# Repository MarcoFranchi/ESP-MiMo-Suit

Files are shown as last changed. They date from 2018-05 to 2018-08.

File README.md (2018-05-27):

# ESP-MiMo-Suit
Lighting MIcroMOdule for Home Automation based on ESP8266 WiFi Module
The MiMo suit is currently composed of three modules:
MiMo-Light (control Light)
MiMo-Button (two buttons)
MiMo-3Realy (three relays)

Common feature:

Compatible with existing electrical plant
minimal changes to the electrical system are necessary, the modules can be installed in the wall box, it is not necessary to install new wires, they can work with pushbuttons or standard switches
Safety and super reliable Buttom/Switch control.
no restriction on the length of the connection wires of the Buttons/Switch (the botton/switch are controlled with the AC Voltage and optoisolated versus the module logic)
Solid State Relay
Optoisolated enad zero cross detect relay for safety and no mechanical and electrical noise
Compatible with ESP Firmware
Espurna, ESP Easy, Tasmota and all firmware for ESP can be used for control

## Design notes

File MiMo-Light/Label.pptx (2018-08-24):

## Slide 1

ESP MiMo-Light
2018- V2.0
By Marco Franchi
Input: 230V/50Hz
Output: 460W MAX!
Unit ID:
Name:

https://github.com/MarcoFranchi/ESP-MiMo-Suit

Switch

Load

F

N

N

AC-in

F

ESP MiMo-Light
2018- V2.0
By Marco Franchi
Input: 230V/50Hz
Output: 460W MAX!
Unit ID:
Name:

https://github.com/MarcoFranchi/ESP-MiMo-Suit

Switch

Load

F

N

N

AC-in

F

ESP MiMo-Light
2018- V2.0
By Marco Franchi
Input: 230V/50Hz
Output: 460W MAX!
Unit ID:
Name:

https://github.com/MarcoFranchi/ESP-MiMo-Suit

Switch

Load

F

N

N

AC-in

F

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

https://github.com/MarcoFranchi/ESP-MiMo-Suit

Switch

Load

F

N

N

AC-in

F

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

https://github.com/MarcoFranchi/ESP-MiMo-Suit

Switch

Load

F

N

N

AC-in

F

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

https://github.com/MarcoFranchi/ESP-MiMo-Suit

Switch

Load

F

N

N

AC-in

F

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

https://github.com/MarcoFranchi/ESP-MiMo-Suit

Switch

Load

F

N

N

AC-in

F

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

https://github.com/MarcoFranchi/ESP-MiMo-Suit

Switch

Load

F

N

N

AC-in

F

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

https://github.com/MarcoFranchi/ESP-MiMo-Suit

Switch

Load

F

N

N

AC-in

F

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

https://github.com/MarcoFranchi/ESP-MiMo-Suit

Switch

Load

F

N

N

AC-in

F

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

https://github.com/MarcoFranchi/ESP-MiMo-Suit

Switch

Load

F

N

N

AC-in

F

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

https://github.com/MarcoFranchi/ESP-MiMo-Suit

Switch

Load

F

N

N

AC-in

F

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

https://github.com/MarcoFranchi/ESP-MiMo-Suit

Switch

Load

F

N

N

AC-in

F

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

https://github.com/MarcoFranchi/ESP-MiMo-Suit

Switch

Load

F

N

N

AC-in

F

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

https://github.com/MarcoFranchi/ESP-MiMo-Suit

Switch

Load

F

N

N

AC-in

F

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

https://github.com/MarcoFranchi/ESP-MiMo-Suit

Switch

Load

F

N

N

AC-in

F

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

https://github.com/MarcoFranchi/ESP-MiMo-Suit

Switch

Load

F

N

N

AC-in

F

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

https://github.com/MarcoFranchi/ESP-MiMo-Suit

Switch

Load

F

N

N

AC-in

F

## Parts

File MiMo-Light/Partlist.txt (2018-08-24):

Partlist

Exported from MiMo-Light-V2.0.brd at 05/06/2018 17:47

EAGLE Version 8.7.0 Copyright (c) 1988-2018 Autodesk, Inc.

Assembly variant: 

Part     Value             Package                        Library             Position (mm)         Orientation

C3       100uF             1210                           SparkFun-Capacitors (2.53 16.26)          MR90
C4       10uF              1206                           SparkFun-Capacitors (41.7 34.62)          MR90
C5       10uF              1206                           SparkFun-Capacitors (28.54 37.3)          MR180
D1                         MINIMELF                       diode               (28.75 33.75)         MR0
FUSE     THERMALFUSE       TE5                            Marco-Lib           (17.63 8.27)          R270
IC1      MID400SD          SOP254P1030X508-8N             SamacSys_Parts      (39.75 18.89)         MR90
IC2      ZLDO1117G33TA     SOT230P700X180-4N              SamacSys_Parts      (35.46 36.24)         MR90
J1       1844252           SHDR6W100P0X350_1X6_2240X920X7 SamacSys_Parts      (21.98 2.38)          R0
JP1                        JP1                            jumper              (22.88 30.7)          R0
K1       CPC1966Y          CPC1966Y                       SamacSys_Parts      (23.2 15.9)           R270
LED2                       CHIPLED_1206                   led                 (22.2 41.05)          R270
LS1      CSS-0575B-SMT-TR  CSS-0575B-SMT-TR               SamacSys_Parts      (22.25 37)            R180
MDL1                       ESP8266-ESP12E                 ESP8266-ESP12E      (10.14 27.93)         R0
R1       220               R1206                          eagle-ltspice       (18.58 25.29)         MR180
R2       10K               R1206                          eagle-ltspice       (34.74 28.85)         MR0
R3       S07K11            S07K11                         varistor            (41.07 6.07)          R270
R4       10K               R1206                          eagle-ltspice       (19.93 19.15)         MR180
R5       1k                R1206                          eagle-ltspice       (29.65 24.6)          MR0
R6       10K               R1206                          eagle-ltspice       (18.48 32.1)          MR0
R7       1k                R1206                          eagle-ltspice       (29.56 21.1)          MR0
R8       1k                R1206                          eagle-ltspice       (18.36 28.9)          MR180
R9       220               R1206                          eagle-ltspice       (41.22 28.85)         MR0
R10      47K 2W            R2512                          eagle-ltspice       (29.44 15.23)         MR180
R12      4K7               R1206                          eagle-ltspice       (28.5 28.75)          MR0
T1       BC817-25LT1SMD    SOT23-BEC                      transistor-npn      (22.75 35.75)         MR0
U2       HLK-PM013W        HLK-PM01                       HLK-PM01            (35.67 25.52)         R90
X2       TSW-104-08-G-D-RA TSW-104-08-G-D-RA              con-samtec          (8.5 8)               R0

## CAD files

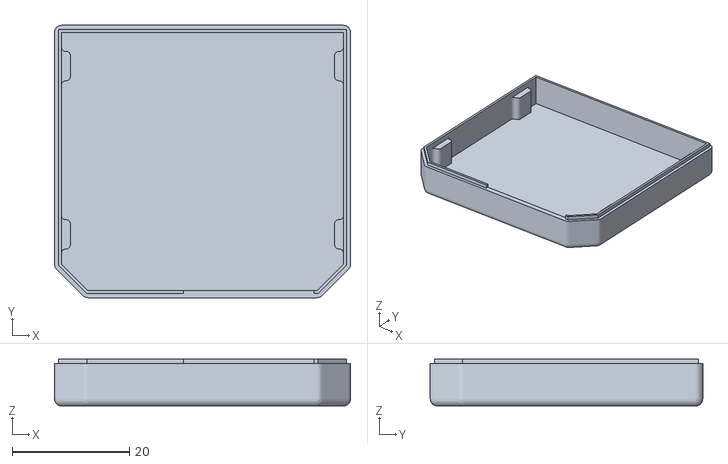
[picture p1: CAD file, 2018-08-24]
MiMo-Light/Buttom.stl
50.4 x 46.4 x 8.00

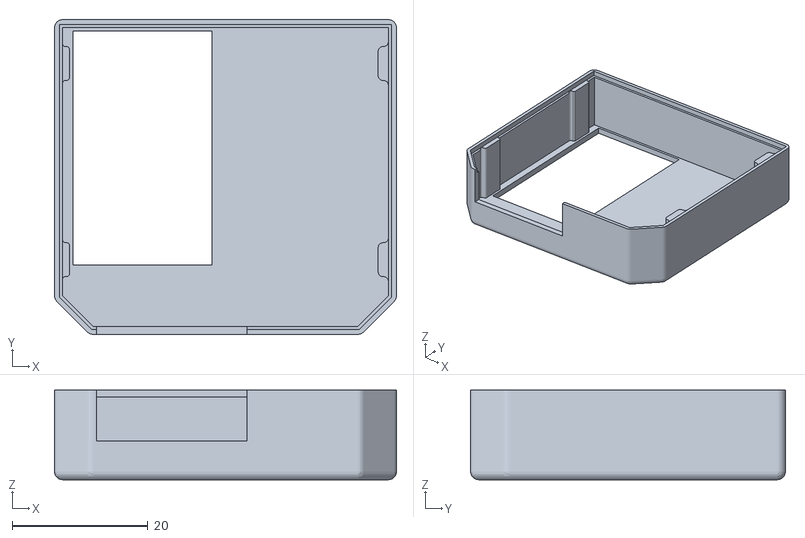
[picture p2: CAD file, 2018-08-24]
MiMo-Light/Top.stl
50.4 x 46.4 x 13.2

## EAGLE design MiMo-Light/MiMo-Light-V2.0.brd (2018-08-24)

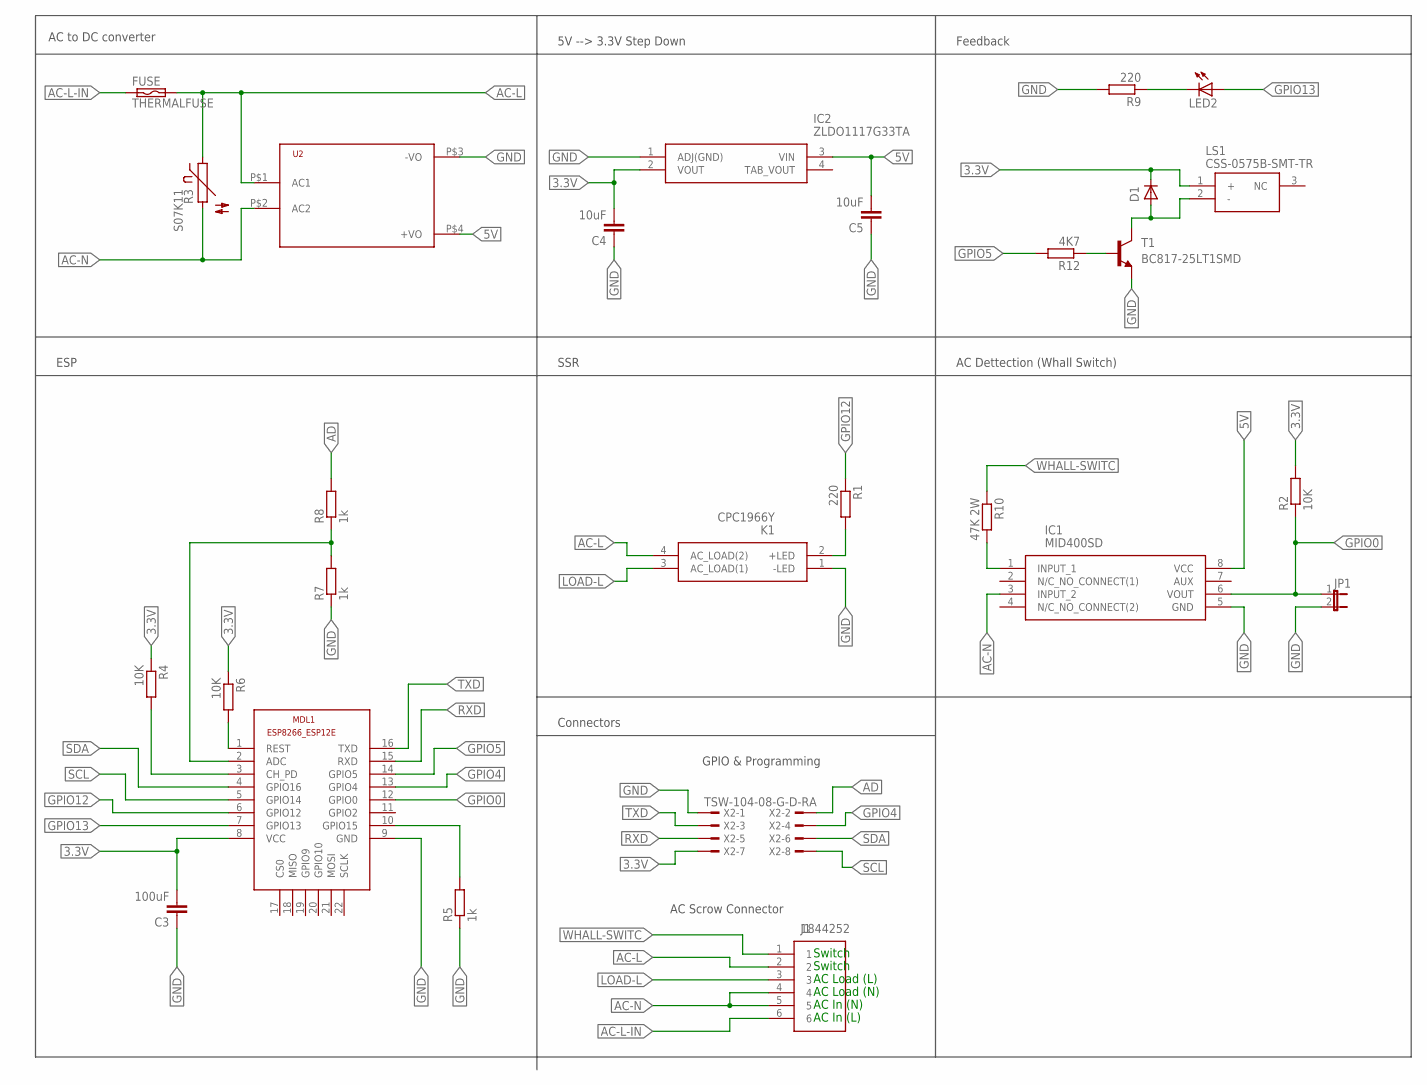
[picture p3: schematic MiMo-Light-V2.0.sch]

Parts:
C3: 100uF; 1210
C4, C5: 10uF; 1206
D1: DIODE-MINIMELF; MINIMELF
FUSE: THERMALFUSE; TE5
IC1: MID400SD; SOP254P1030X508-8N
IC2: ZLDO1117G33TA; SOT230P700X180-4N
J1: 1844252; SHDR6W100P0X350_1X6_2240X920X7
JP1: JP1E; JP1
K1: CPC1966Y
LED2: LEDCHIPLED_1206; CHIPLED_1206
LS1: CSS-0575B-SMT-TR
MDL1: ESP8266-12EESP8266-ESP12E; ESP8266-ESP12E
R1, R9: 220; R1206
R2, R4, R6: 10K; R1206
R3: S07K11
R5, R7, R8: 1k; R1206
R10: 47K 2W; R2512
R12: 4K7; R1206
T1: BC817-25LT1SMD; SOT23-BEC
U2: HLK-PM013W; HLK-PM01
X2: TSW-104-08-G-D-RA

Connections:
3.3V: C3.2, C4.2, D1.C, IC2.2 (VOUT), LS1.1 (+), MDL1.8 (VCC), R2.2, R4.1, R6.1, X2.7
5V: C5.2, IC1.8 (VCC), IC2.3 (VIN), U2.P$4 (+VO)
AC-DETECT: IC1.1 (INPUT_1), R10.2
AC-L: FUSE.2, J1.2, K1.4 (AC_LOAD(2)), R3.1, U2.P$1 (AC1)
AC-L-IN: FUSE.1, J1.6
AC-N: IC1.3 (INPUT_2), J1.4, J1.5, R3.2, U2.P$2 (AC2)
AD: R8.2, X2.2
ADC: MDL1.2 (ADC), R7.2, R8.1
GND: C3.1, C4.1, C5.1, IC1.5 (GND), IC2.1 (ADJ(GND)), JP1.2, K1.1 (-LED), MDL1.9 (GND), R5.1, R7.1, R9.2, T1.E, U2.P$3 (-VO), X2.1
GPIO0: IC1.6 (VOUT), JP1.1, MDL1.12 (GPIO0), R2.1
GPIO4: MDL1.13 (GPIO4), X2.4
GPIO5: MDL1.14 (GPIO5), R12.2
GPIO12: MDL1.6 (GPIO12), R1.1
GPIO13: LED2.A, MDL1.7 (GPIO13)
LOAD-L: J1.3, K1.3 (AC_LOAD(1))
unnamed: LED2.C, R9.1
unnamed: K1.2 (+LED), R1.2
unnamed: D1.A, LS1.2 (-), T1.C
unnamed: MDL1.3 (CH_PD), R4.2
unnamed: R12.1, T1.B
unnamed: MDL1.10 (GPIO15), R5.2
unnamed: MDL1.1 (REST), R6.2
RXD: MDL1.15 (RXD), X2.5
SCL: MDL1.5 (GPIO14), X2.8
SDA: MDL1.4 (GPIO16), X2.6
TXD: MDL1.16 (TXD), X2.3
WHALL-SWITC: J1.1, R10.1

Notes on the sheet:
SSR
AC to DC converter
5V --> 3.3V Step Down
Feedback
AC Dettection (Whall Switch)
Connectors
GPIO & Programming
AC Scrow Connector
Switch
AC Load (L)
AC Load (N)
AC In (N)
AC In (L)
ESP

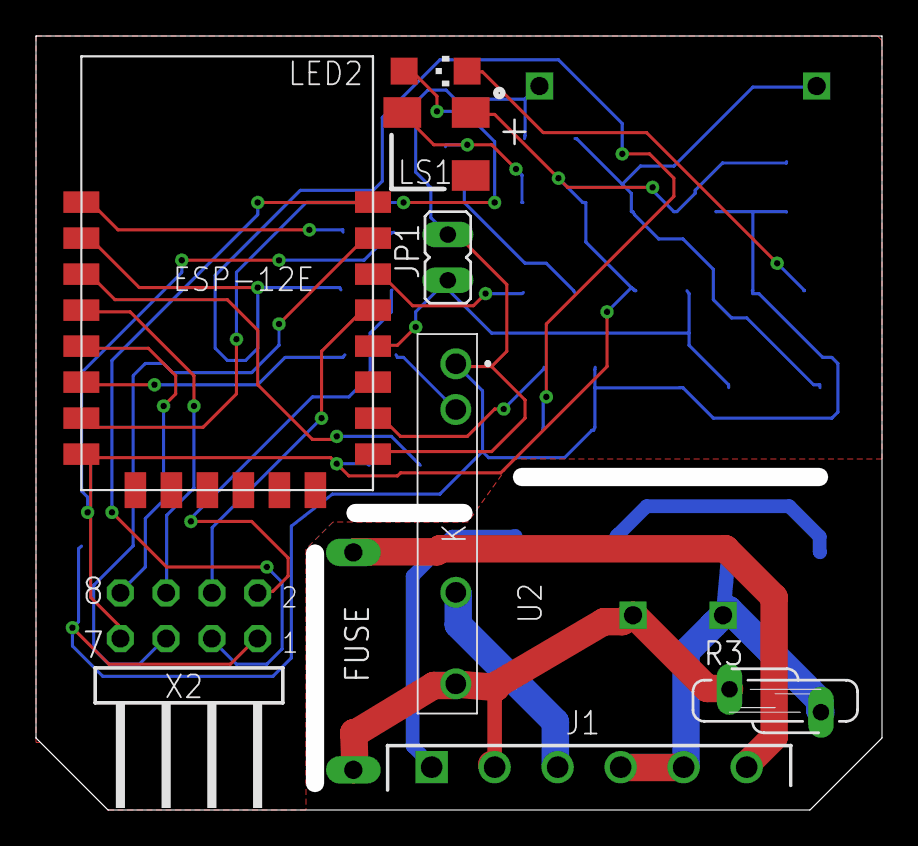
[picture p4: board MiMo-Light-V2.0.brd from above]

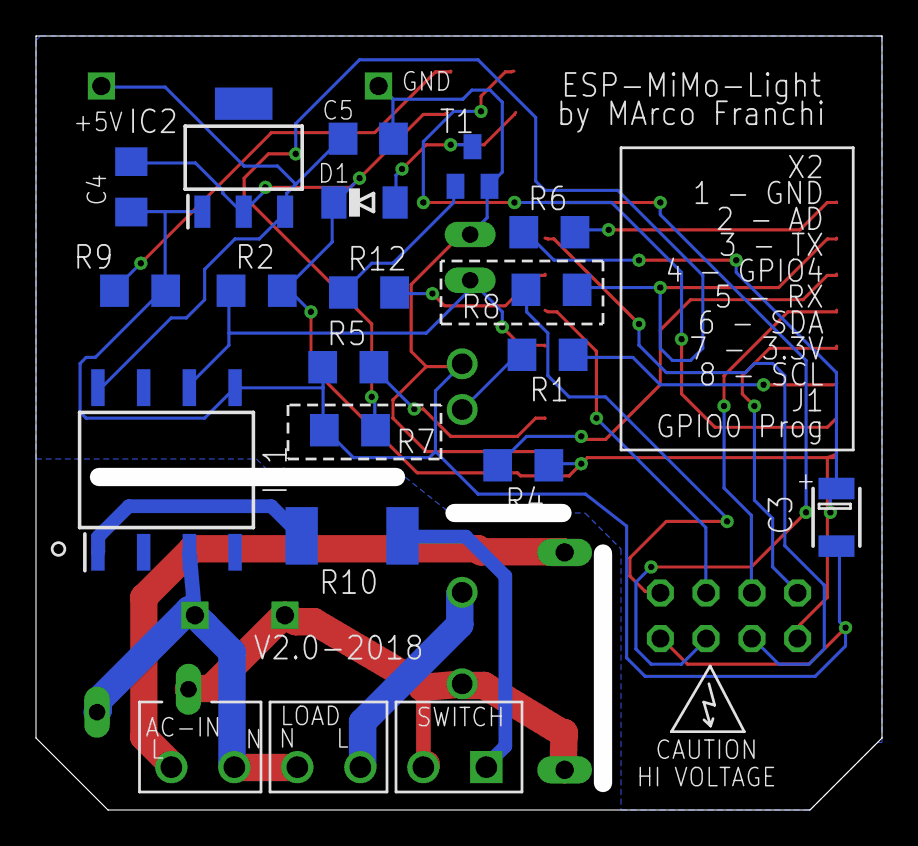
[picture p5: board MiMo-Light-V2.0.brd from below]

Board: 2 copper layers, 47.0 x 43.0 mm, 27 parts (17 on the bottom side), 27 nets.

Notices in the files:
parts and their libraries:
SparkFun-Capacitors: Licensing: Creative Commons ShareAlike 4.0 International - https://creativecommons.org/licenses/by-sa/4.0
